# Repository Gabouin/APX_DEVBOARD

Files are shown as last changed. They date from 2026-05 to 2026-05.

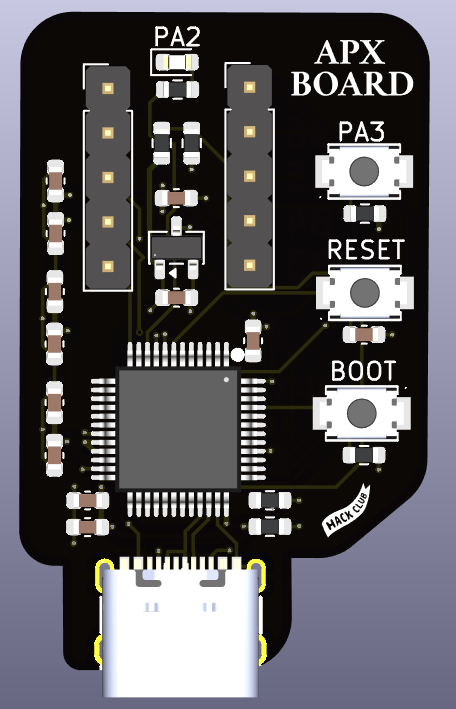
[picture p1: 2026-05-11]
images/Capture d'écran 2026-05-12 010746.png

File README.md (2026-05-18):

<h1 align="center">
  <br>
  
  <br>
  APX DEVBOARD
  <br>
</h1>

<h4 align="center">
A STM32 based devboard with Buttons, a LED and 8 GPIO pins.
</h4>

<div align="center">






</div>

<p align="center">
  <a href="#about-the-project">About</a> •
  <a href="#repository-structure">Structure</a> •
  <a href="#schematic-on-kicad">Schematic</a> •
  <a href="#pcb-on-kicad">PCB</a> •
  <a href="#CAD">CAD</a> •
  <a href="#bill-of-materials">BOM</a> •
  <a href="#license">License</a> •
  <a href="#credits">Credits</a>
</p>

<br>
<br>
<p align=center>
banner

</p>

## About the Project

**APX DEVBOARD** is a STM32 based devboard designed with GPIO pins, buttons and an LED

### Features

- **STM32G431CBT6** MCU 32-Bit 170MHz 128KB (128K x 8) FLASH 48-LQFP (7x7)
- **8 GPIO pins** to help make any hardware project
- **GPIO linked LED** to program it without needing an external LED
- **GPIO linked button** to use it without needing an external button
- **BOOT and RESET buttons**
- **USB-C input**
- **Amiri silkscreen** for a professional look
- **Original edge cut** to look cool lol
- **Small size** of 2.3*3.7 cm

## Repository Structure

- `src/` — KiCad and Fusion360 project sources
- `production/` — PCB and CAD fabrication files (Gerbers, BOM, Pick & Place, 3mf)
- `images/` — images used in the README and documentation

## Schematic on KiCad

Source : `src/schem`  

Capture d'écran 2026-05-12 005443

## PCB on KiCad

Source : `src/pcb/`  

<div align="center">
  <table>
    <tr>
      <td valign="bottom"></td>
      <td valign="bottom">Capture d'écran 2026-05-12 010605</td>
      <td valign="bottom">Capture d'écran 2026-05-12 010555</td>
  </table>
</div>
<div align="center">
  <table>
    <tr>
      <td valign="bottom">Capture d'écran 2026-05-12 010746</td>
      <td valign="bottom">Capture d'écran 2026-05-12 010754</td>
  </table>
</div>  

> The PCB design is made on only 2 layers, to reduce the cost of the board !  

<br>

## Share Links

go check out the pcb on [KiCanva](https://kicanvas.org/?github=https://github.com/Gabouin/APX_DEVBOARD/blob/main/src/APX%20Devboard.kicad_pcb) !
<br>
go check out the case on [Fusion360](https://a360.co/4uNEBf6) !

<br>

## CAD

Source : `src/CAD` and
         `production/CAD`

<div align="center">
  <table>
    <tr>
      <td valign="bottom">Capture d'écran 2026-05-19 003227</td>
      <td>Capture d'écran 2026-05-19 003627</td>
    </tr>
  </table>
</div>

> The case use snap fits as there is no mounting hole in the PCB.

<br>

## Bill of Materials

Source: `production/pcb/bom.csv`

|Designator |Footprint |Quantity|Value |LCSC Part #|
|---|---|---|---|---|
|PA2 |0603 |1 |LED |C2286 |
|BOOT |SW-SMD_L3.9-W3.0-P4.45 |1 |BOOT |C455280 |
|C11, C12, C5, C6, C8 |0603 |5 |1uF |C15849 |
|C1, C10, C2, C3, C4, C7 |0603 |6 |100nF |C14663 |
|C9 |0603 |1 |10nF |C57112 |
|DEBUG |PinHeader_1x04_P2.54mm_Vertical |1 |Conn_01x04 |C2691448 |
|J1 |PinHeader_1x05_P2.54mm_Vertical |1 |Header Left |C124379 |
|J2 |PinHeader_1x05_P2.54mm_Vertical |1 |Header Right |C124379 |
|PA3 |SW-SMD_L3.9-W3.0-P4.45 |1 |PA3 |C455280 |
|R1, R2 |0603 |2 |100k |C23186 |
|R3, R4, R7 |0603 |3 |10k |C25804 |
|R6, R5 |0603 |2 |5.1k |C25803 |
|RESET |SW-SMD_L3.9-W3.0-P4.45 |1 |RESET |C455280 |
|STM32 |LQFP-48_L7.0-W7.0-P0.50-LS9.0-BL|1 |STM32G431CBT6 |C529355 |
|U1 |SOT-23-3 |1 |XC6206PxxxMR |C5446 |
|USB-C1 |USB-C-SMD_TYPE-C-16PIN-2MD-073  |1 |TYPE-C 16PIN 2MD|C2765186 |

## JLPCB order

<div align="center">
  <table>
    <tr>
      <td valign="bottom"></td>
      <td valign="bottom"></td>
  </table>
</div>  

## You might also like

- [APX USB HUB](https://github.com/gabouin/APX-USB-HUB) - A PTC-secured USB HUB designed for [Macondo - Hack Club](https://macondo.hackclub.com)
- [HackPad](https://github.com/Gabouin/Hackpad) - A 6-keys macropad designed for [Blueprint - Hack Club](https://blueprint.hackclub.com)
- See more in my [github](https://github.com/gabouin)

## License

This project is licensed under the **MIT License** — see the [LICENSE](LICENSE) file for details.

## Credits

This project uses:

- **KiCad** - PCB design and schematic capture
- **JLCPCB** - PCB manufacturing
- **LCSC** - Parts order
- **Figma** - Silkscreen and banner design
- **Fusion 360** - CAD
- **[@NotARoomba](https://github.com/notaroomba)** - Readme template

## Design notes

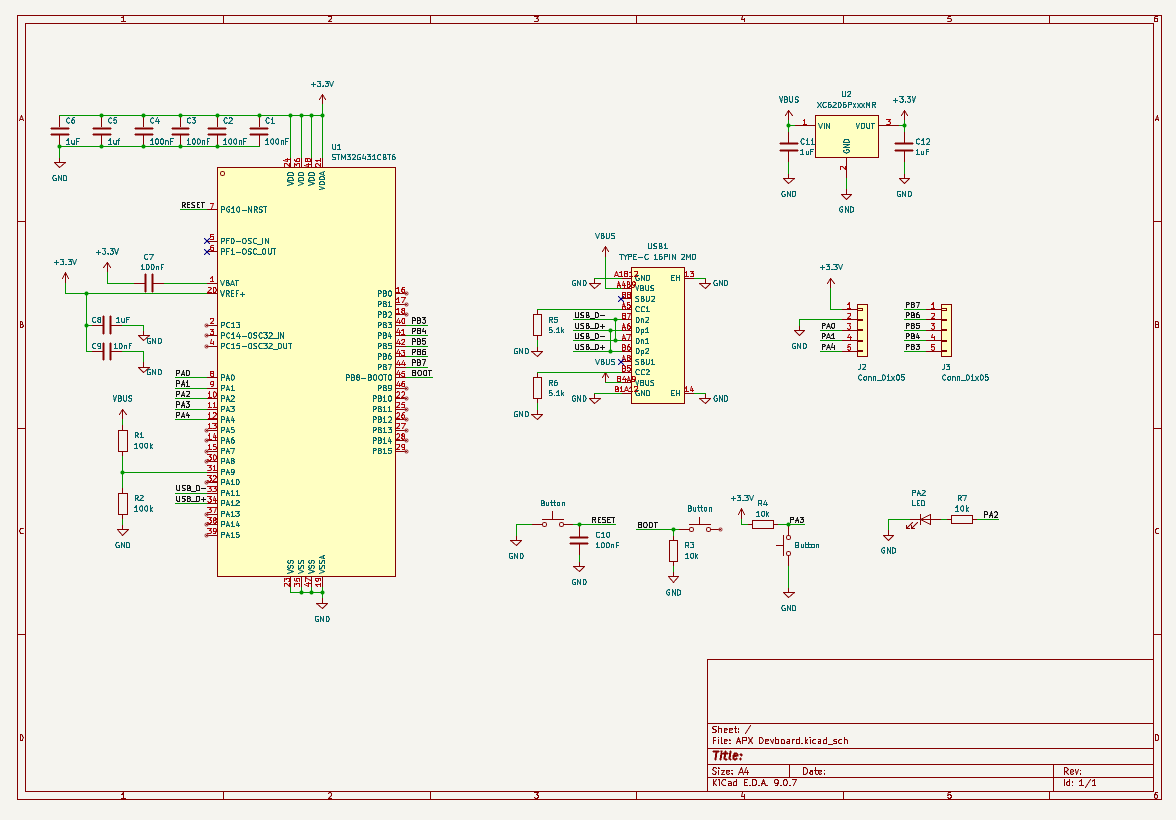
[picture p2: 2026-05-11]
images/Capture d'écran 2026-05-12 005443.png

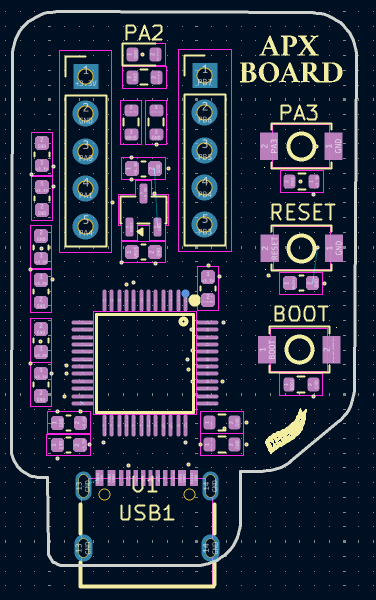
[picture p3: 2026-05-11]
images/Capture d'écran 2026-05-12 010555.png

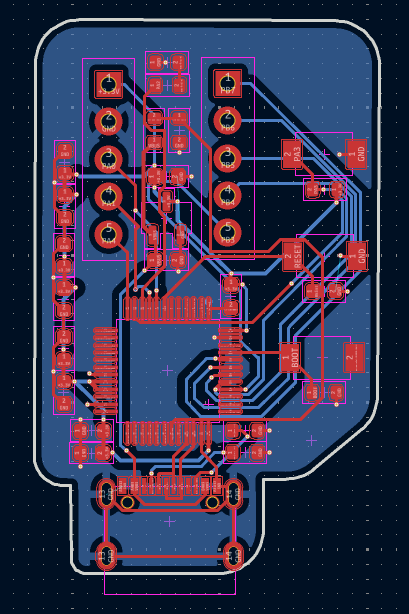
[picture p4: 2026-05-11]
images/Capture d'écran 2026-05-12 010623.png

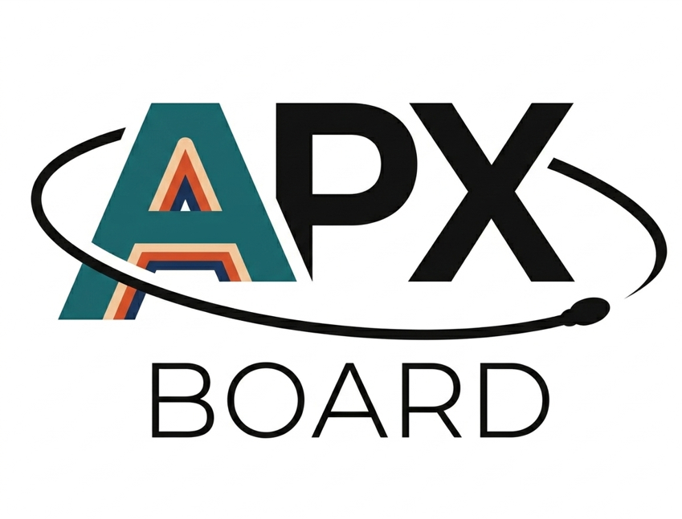
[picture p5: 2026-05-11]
images/Capture d'écran 2026-05-12 004848.png

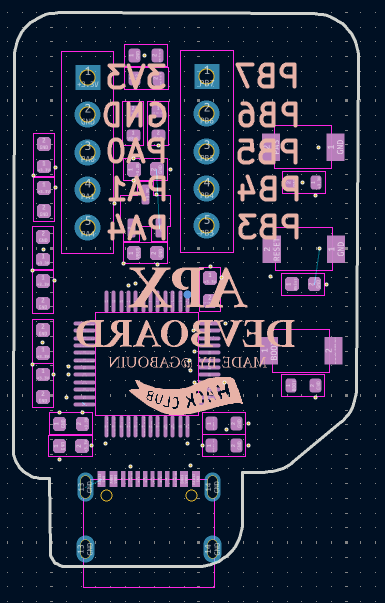
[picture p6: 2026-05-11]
images/Capture d'écran 2026-05-12 010605.png

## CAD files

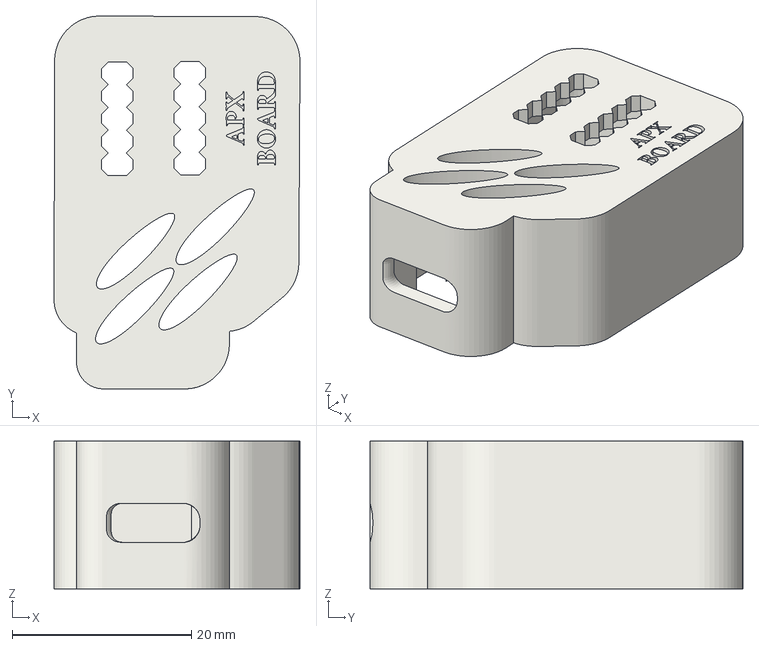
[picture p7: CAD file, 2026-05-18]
production/CAD/case top.3mf
27.4 x 41.6 x 16.5 mm

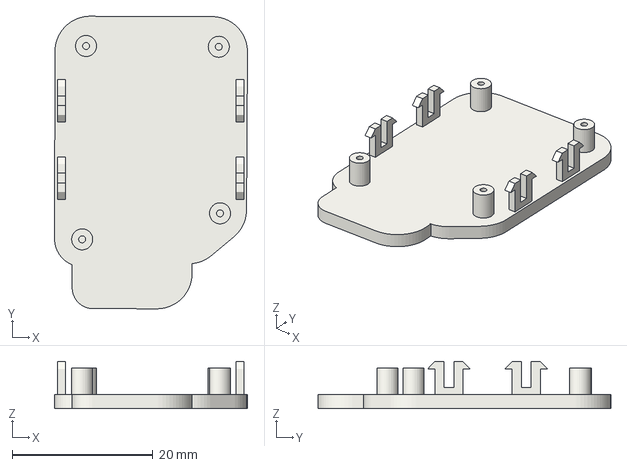
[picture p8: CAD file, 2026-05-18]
production/CAD/case bottom.3mf
27.4 x 41.6 x 6.70 mm

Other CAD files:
src/CAD/board.step

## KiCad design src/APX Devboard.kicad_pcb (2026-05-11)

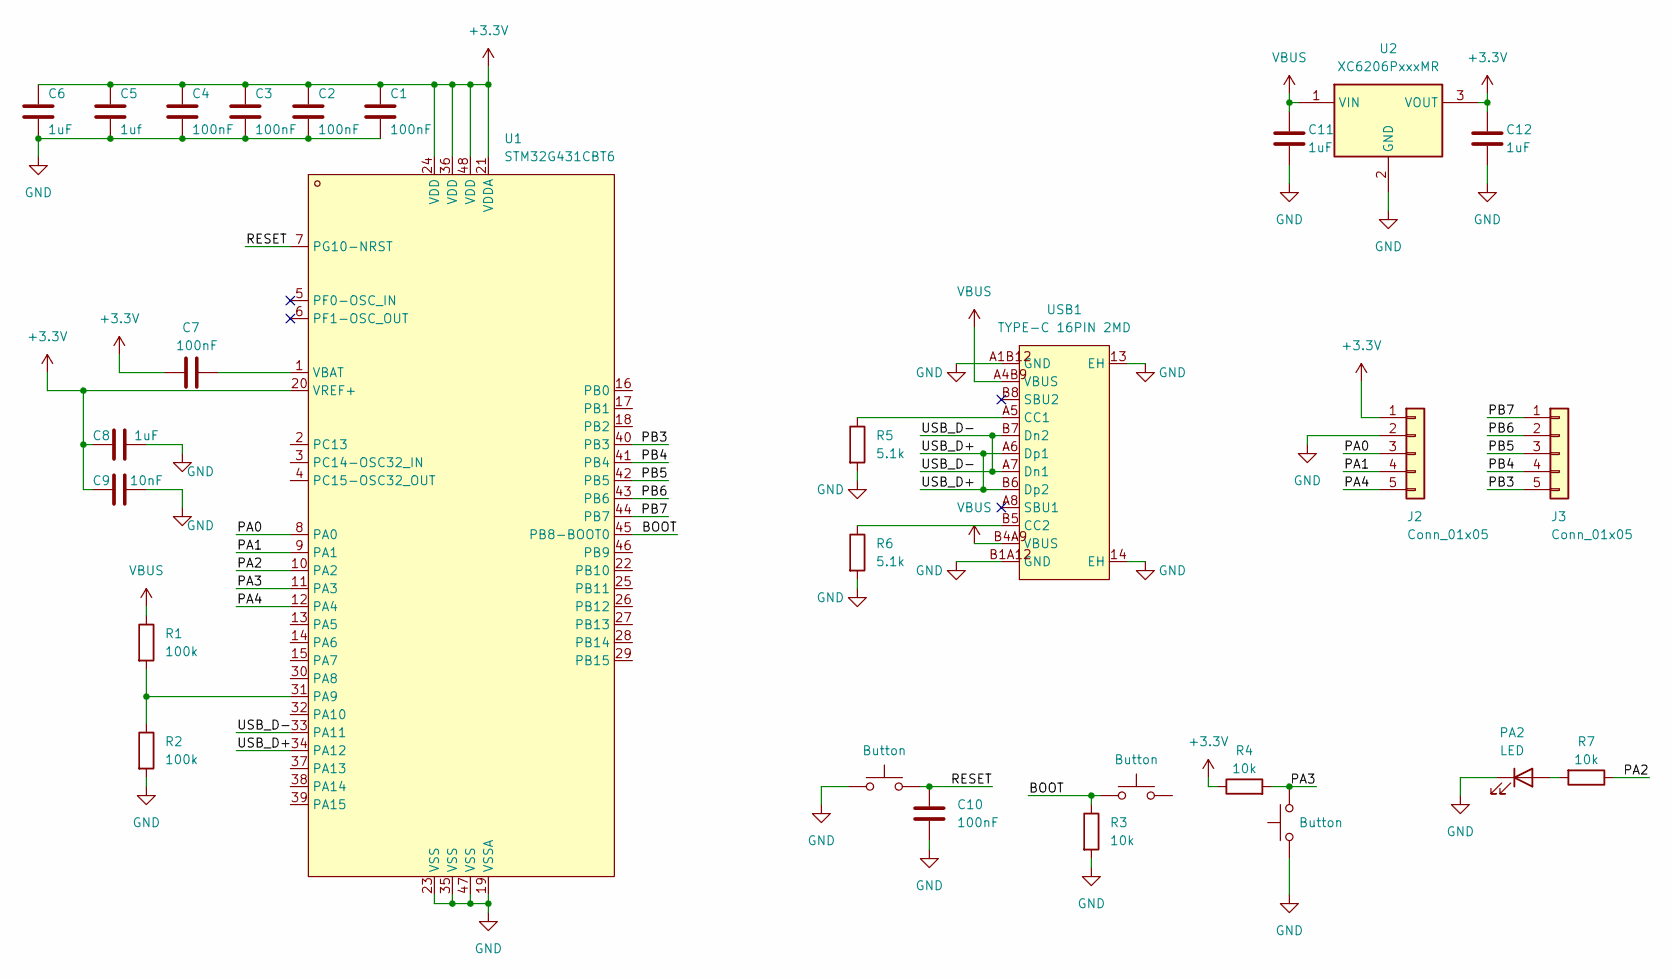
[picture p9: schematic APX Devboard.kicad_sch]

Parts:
BOOT1: Button; SW-SMD_L3.9-W3.0-P4.45
C1, C2, C3, C4, C7, C10: 100nF; C_0603_1608Metric
C5: 1uf; C_0603_1608Metric
C6, C8, C11, C12: 1uF; C_0603_1608Metric
C9: 10nF; C_0603_1608Metric
J2, J3: Conn_01x05; PinHeader_1x05_P2.54mm_Vertical
PA2: LED; LED_0603_1608Metric
PA3: Button; SW-SMD_L3.9-W3.0-P4.45
R1, R2: 100k; R_0603_1608Metric
R3, R4, R7: 10k; R_0603_1608Metric
R5, R6: 5.1k; R_0603_1608Metric
RESET1: Button; SW-SMD_L3.9-W3.0-P4.45
U1: STM32G431CBT6; LQFP-48_L7.0-W7.0-P0.50-LS9.0-BL; MPN STM32G431CBT6; LCSC Part C529355
U2: XC6206PxxxMR; SOT-23-3
USB1: TYPE-C 16PIN 2MD; USB-C-SMD_TYPE-C-16PIN-2MD-073; MPN TYPE-C 16PIN 2MD(073); LCSC Part C2765186

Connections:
+3.3V: C1.1, C2.1, C3.1, C4.1, C5.1, C6.1, C7.1, C8.2, C9.2, C12.1, J2.1, R4.1, U1.20 (VREF+), U1.21 (VDDA), U1.24 (VDD), U1.36 (VDD), U1.48 (VDD), U2.3 (VOUT)
/BOOT: BOOT1.1, R3.1, U1.45 (PB8-BOOT0); also elsewhere on the board
/PA0: J2.3, U1.8 (PA0)
/PA1: J2.4, U1.9 (PA1)
/PA2: R7.1, U1.10 (PA2)
/PA3: PA3.2, R4.2, U1.11 (PA3)
/PA4: J2.5, U1.12 (PA4)
/PB3: J3.5, U1.40 (PB3)
/PB4: J3.4, U1.41 (PB4)
/PB5: J3.3, U1.42 (PB5)
/PB6: J3.2, U1.43 (PB6)
/PB7: J3.1, U1.44 (PB7)
/RESET: C10.1, RESET1.2, U1.7 (PG10-NRST); also elsewhere on the board
/USB_D+: U1.34 (PA12), USB1.A6 (Dp1), USB1.B6 (Dp2)
/USB_D-: U1.33 (PA11), USB1.A7 (Dn1), USB1.B7 (Dn2)
GND: C1.2, C2.2, C3.2, C4.2, C5.2, C6.2, C8.1, C9.1, C10.2, C11.2, C12.2, J2.2, PA2.1 (K), PA3.1, R2.2, R3.2, R5.2, R6.2, RESET1.1, U1.19 (VSSA), U1.23 (VSS), U1.35 (VSS), U1.47 (VSS), U2.2 (GND), USB1.13 (EH), USB1.14 (EH), USB1.A1B12 (GND), USB1.B1A12 (GND); also elsewhere on the board
unnamed: PA2.2 (A), R7.2
unnamed: R1.2, R2.1, U1.31 (PA9)
unnamed: C7.2, U1.1 (VBAT)
unnamed: R5.1, USB1.A5 (CC1)
unnamed: R6.1, USB1.B5 (CC2)
VBUS: C11.1, R1.1, U2.1 (VIN), USB1.A4B9 (VBUS), USB1.B4A9 (VBUS)

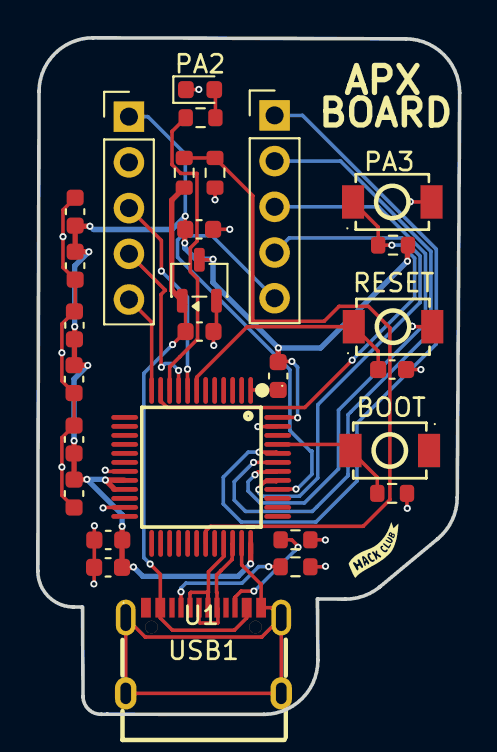
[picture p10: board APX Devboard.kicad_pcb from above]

Board: 2 copper layers, 23.4 x 37.6 mm, 28 parts (0 on the bottom side), 22 nets.

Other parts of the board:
BOOT: Button; SW-SMD_L3.9-W3.0-P4.45
RESET: Button; SW-SMD_L3.9-W3.0-P4.45

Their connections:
/BOOT: BOOT.1; also elsewhere on the board
/RESET: RESET.2; also elsewhere on the board
GND: RESET.1; also elsewhere on the board

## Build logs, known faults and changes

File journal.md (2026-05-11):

https://lapse.hackclub.com/timelapse/ha-rk0ZAF1Hp - The one and only session for this project. I already had experience with devboards so it was pretty easy !

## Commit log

2026-05-11 Rename APX Devboard.kicad_pro to src/APX Devboard.kicad_pro
2026-05-18 Rename APX Devboard.step to board.step
    [board.step]
2026-05-18 Rename production/case bottom.3mf to production/CAD/case bottom.3mf
    [case bottom.3mf]
2026-05-18 Rename production/case top.3mf to production/CAD/case top.3mf
    [case top.3mf]

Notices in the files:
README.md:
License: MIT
